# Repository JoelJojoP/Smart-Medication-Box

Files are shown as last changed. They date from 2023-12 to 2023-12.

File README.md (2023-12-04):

# Smart-Medication-Box

## Introduction

A considerable percentage of the elderly population takes medicines regularly. Sometimes, they forget to take their medication, which may lead to severe repercussions. This project aims to enhance medication adherence by developing a medicine box with personalized reminders for users to take their medications at user-defined times.

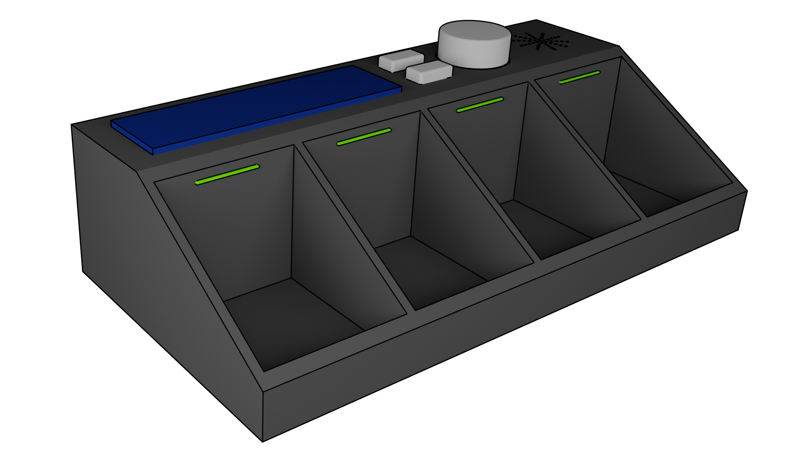
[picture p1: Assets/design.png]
Concept Design


## Technologies Used

Tech Used

## Implementation

- The whole project is based on Teensy 4.1 microcontroller.
- Users can set, modify or remove reminders using the rotary encoders and push button on the box.
- The box can give visual and auditory alerts using the LEDs on each rack and the buzzer.
- The inbuilt RTC of the microcontroller helps in keeping track of time.
- The user data and preferences are stored on an SD card attached to the Teensy.
- A 3D printed case is created to house all the electronics.

## Schematics

The circuit has been made on Fritzing. [Here](/Circuit_Diagram.fzz) is the Fritzing file.

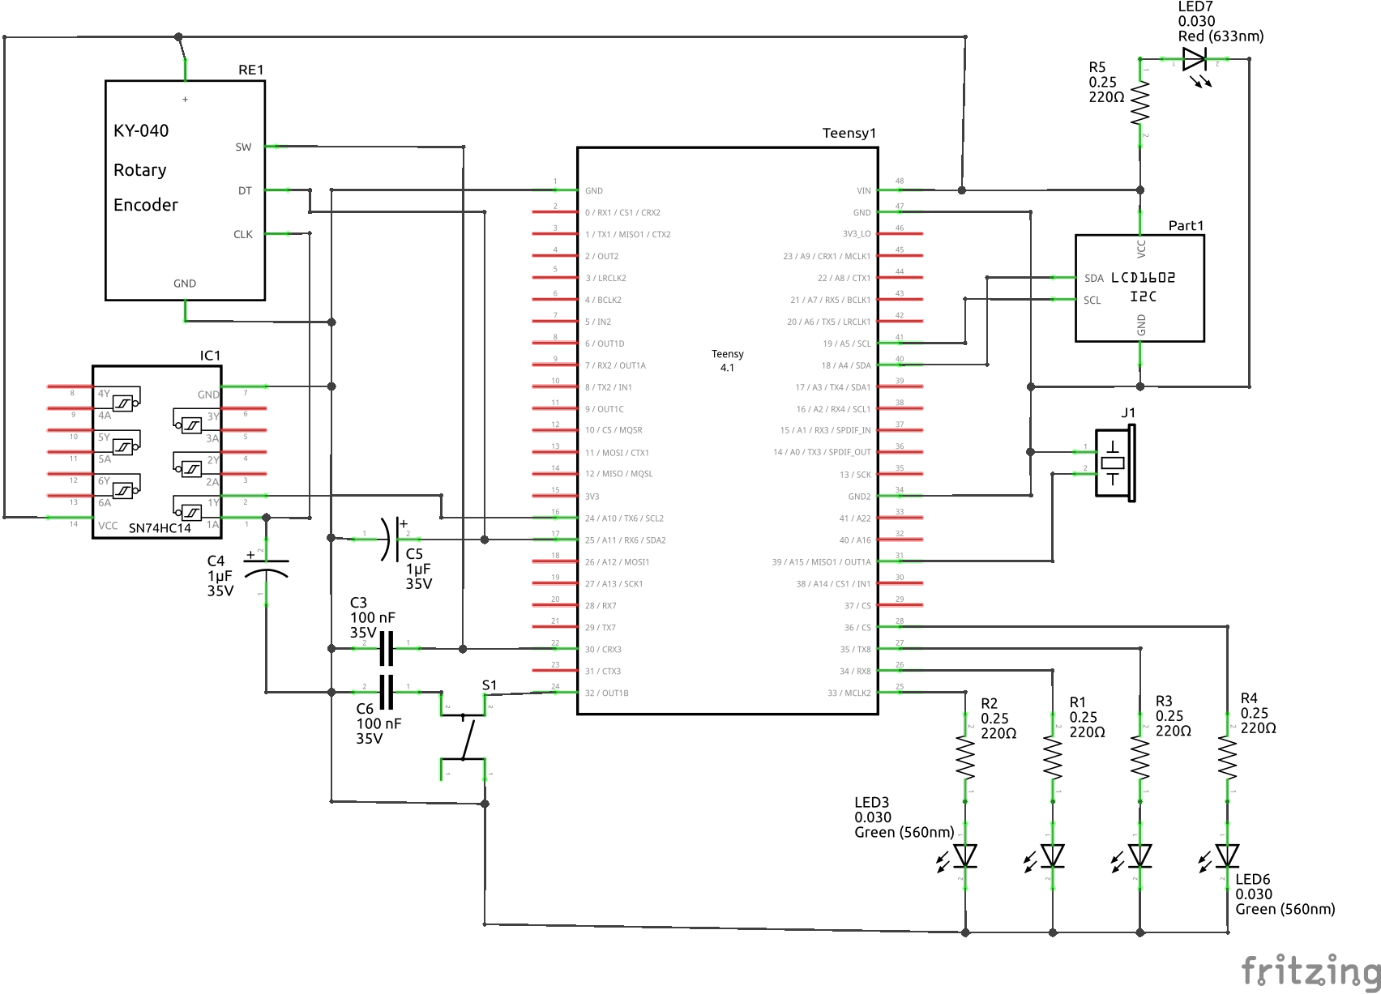
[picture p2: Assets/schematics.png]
Schematics


> **Note:**
> - We have wired the clk of the rotary encoder to a 7414 Hex Schmitt Trigger IC because the signals from the encoders were noisy. This is not necessary and the clk of the encoder can be wired directly to the teensy if the rotary encoder works fine.
> - Other than these connections, make sure to hook up a coin cell Li-Ion battery to the VBat pin right behind the SD card slot. This battery will be used to power the RTC even when the Teensy is switched off.

## Design of the Medication Box

The medication box was designed in OnShape. The ```.stl``` files can be taken from [here](/Models). To edit the model, [here](https://cad.onshape.com/documents/3bb37c6f5c3fc5625ebe736c/w/5e6eef892a42bb9e06b4f36b/e/434df4fac0757aec08d6021b) is the link to the OnShape document.

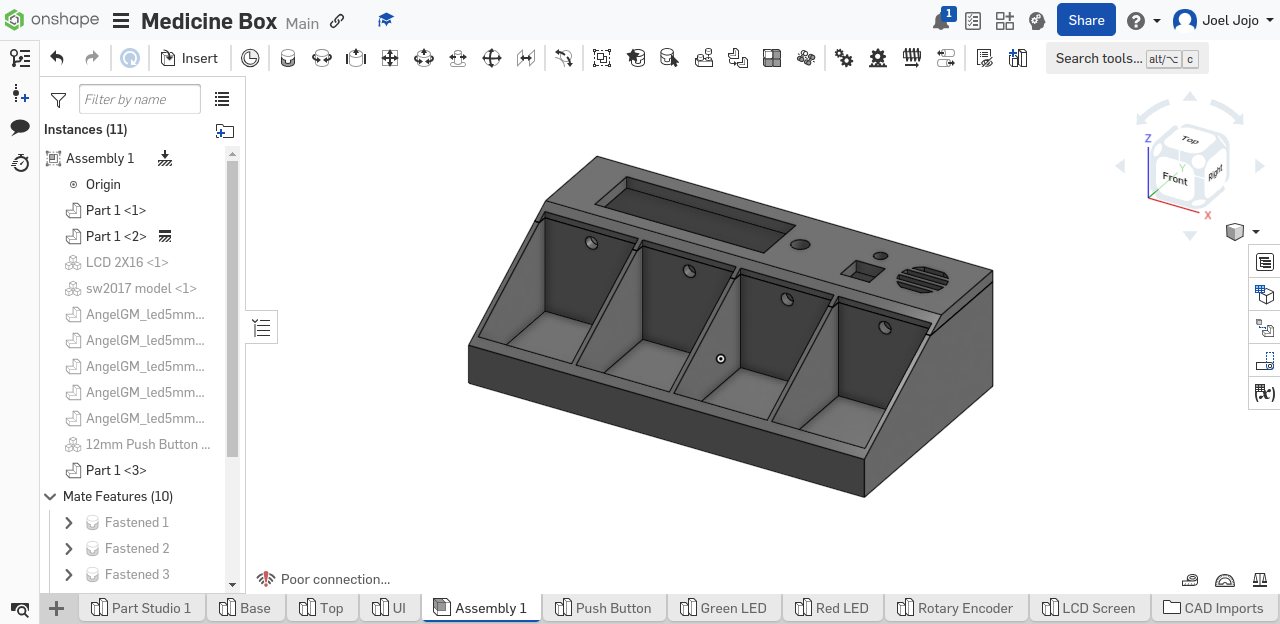
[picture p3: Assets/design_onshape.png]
Model


## Everything Put Together

After testing the circuits, rigging the circuit on a perfboard and placing all the components inside the 3D print, this is how it looks at the end.

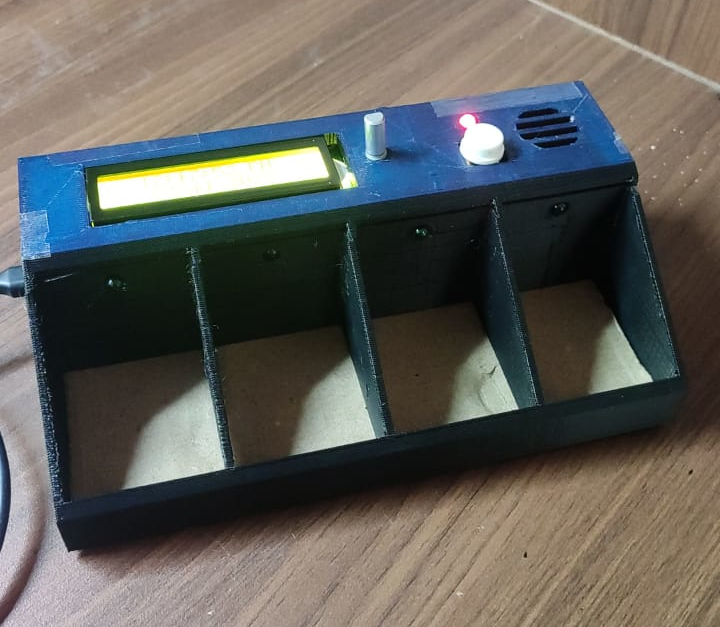
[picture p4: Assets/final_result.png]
Final Result


## Future Scope

- Improving portability by using rechargeable batteries.
- Integrating the medication box with mobile applications.
- Enable IoT connectivity toprovide remote monitoring features for healthcare providers.
- Implement machine learning to provide personalized insights and predictions to optimize medication adherence.
- Extend the capabilities of the medication box to accommodate a broader range of medication types.

## Project Members

1. [Joel Jojo Painuthara](https://github.com/JoelJojoP)
2. [Jalak Jignesh Kamdar](https://github.com/jalakjk13)

## License

This repository is licensed under the [MIT License](https://github.com/JoelJojoP/Smart-Medication-Box/blob/main/LICENSE)

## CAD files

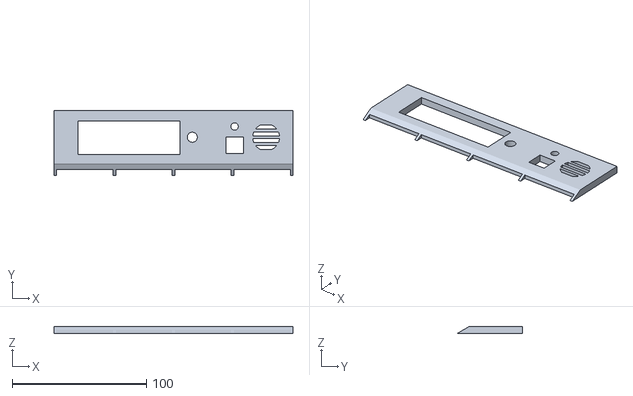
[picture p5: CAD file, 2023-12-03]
Models/Top.stl
178.0 x 48.6 x 5.00

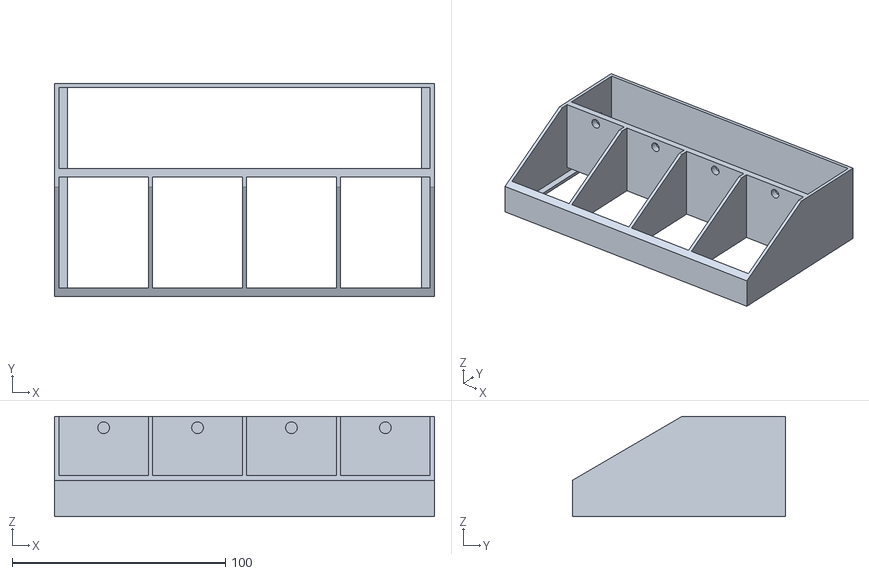
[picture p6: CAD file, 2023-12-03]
Models/Body.stl
178.0 x 100.0 x 47.0

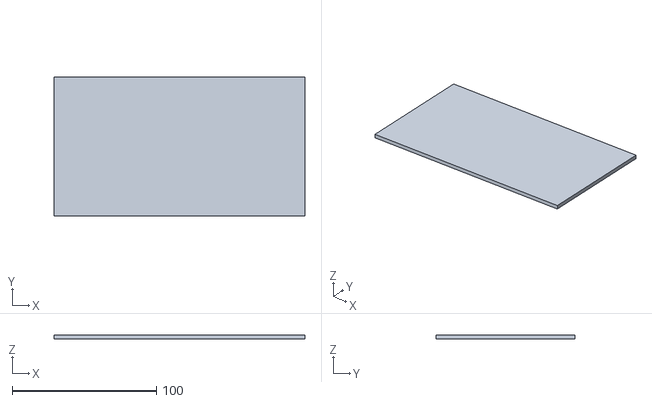
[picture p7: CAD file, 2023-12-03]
Models/Base.stl
173.8 x 96.0 x 3.00

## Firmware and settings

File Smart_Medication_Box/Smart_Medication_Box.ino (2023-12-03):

// Teensy 4.1 code for Smart Medication Box

#include <Wire.h>
#include <LiquidCrystal_I2C.h>
#include <TimeLib.h>
#include <SD.h>
#include <SPI.h>

#define TIME_HEADER "T"

// Pins for various components
#define enc_clk 24
#define enc_dt 25
#define menu_button 32
#define select_button 30
#define buzzer_pin 39
int Rack_LED[4] = {33, 34, 35, 36};

// SD Card chip select - BUILTIN_SDCARD to use the built-in SD card slot of Teensy 4.1
const int chipSelect = BUILTIN_SDCARD;

// File object for SD card
File myFile;

// LCD object - 0x27 is the default I2C address of the I2C LCD module
LiquidCrystal_I2C lcd(0x27, 16, 2); // set the LCD address to 0x27 for a 16 chars and 2 line display

// Variables for various state controls
volatile int state = 0;
volatile int substate = 0;
volatile int rack = 0;
volatile int time_slot = 0;
volatile int reset_opt = 0;
volatile int edit_mode = 0;
int alert[4] = {0, 0, 0, 0};

String isEvening = "AM";
int h, m, prev_h, prev_m;
String r_buff;
int write_change = 0;

// Arrays to store the time for each rack
int slot_hour[4][4] = {{0, 0, 0, 0}, {0, 0, 0, 0}, {0, 0, 0, 0}, {0, 0, 0, 0}};
int slot_minute[4][4] = {{0, 0, 0, 0}, {0, 0, 0, 0}, {0, 0, 0, 0}, {0, 0, 0, 0}};
String slot_script[4][4] = {{"AM", "AM", "AM", "AM"}, {"AM", "AM", "AM", "AM"}, {"AM", "AM", "AM", "AM"}, {"AM", "AM", "AM", "AM"}};

// Functions to get time from Teensy's inbuilt RTC
time_t getTeensy3Time()
{
  return Teensy3Clock.get();
}

unsigned long processSyncMessage()
{
  unsigned long pctime = 0L;
  const unsigned long DEFAULT_TIME = 1357041600;

  if (Serial.find(TIME_HEADER))
  {
    pctime = Serial.parseInt();
    return pctime;
    if (pctime < DEFAULT_TIME)
    {
      pctime = 0L;
    }
  }
  return pctime;
}

// Function to print digits on LCD
void printDigits(int digits)
{
  if (digits < 10)
    lcd.print("0");
  lcd.print(digits);
}

// State control functions
void change_option()
{
  if (digitalRead(enc_dt) == 0)
  {
    if (state == 1 && substate == 0)
    {
      rack--;
      if (rack <= -1)
        rack = 3;
    }
    else if (substate == 1)
    {
      time_slot--;
      if (time_slot <= -1)
        time_slot = 3;
    }
    else if (substate == 2)
    {
      if (edit_mode == 0)
      {
        slot_hour[rack][time_slot]--;
        if (slot_hour[rack][time_slot] <= -1)
          slot_hour[rack][time_slot] = 12;
      }
      else if (edit_mode == 1)
      {
        slot_minute[rack][time_slot]--;
        if (slot_minute[rack][time_slot] <= -1)
          slot_minute[rack][time_slot] = 59;
      }
      else if (edit_mode == 2)
      {
        slot_script[rack][time_slot] = (slot_script[rack][time_slot] == "AM") ? "PM" : "AM";
      }
    }
  }
  else
  {
    if (state == 1 && substate == 0)
    {
      rack++;
      if (rack >= 4)
        rack = 0;
    }
    else if (substate == 1)
    {
      time_slot++;
      if (time_slot >= 4)
        time_slot = 0;
    }
    else if (substate == 2)
    {
      if (edit_mode == 0)
      {
        slot_hour[rack][time_slot]++;
        if (slot_hour[rack][time_slot] >= 13)
          slot_hour[rack][time_slot] = 0;
      }
      else if (edit_mode == 1)
      {
        slot_minute[rack][time_slot]++;
        if (slot_minute[rack][time_slot] >= 60)
          slot_minute[rack][time_slot] = 0;
      }
      else if (edit_mode == 2)
      {
        slot_script[rack][time_slot] = (slot_script[rack][time_slot] == "AM") ? "PM" : "AM";
      }
    }
  }
}

void change_state()
{
  if (digitalRead(menu_button) == 0)
  {
    int f = 0;
    for (int i = 0; i < 4; i++)
    {
      if (alert[i] != 0)
      {
        alert[i] = 0;
        f = 1;
      }
    }
    if (f == 0)
    {
      substate = 0;
      state++;
      if (state == 2)
        state = 0;
    }
  }
}

void select_opt()
{
  if (digitalRead(select_button) == 0 && state == 1 && substate == 0)
  {
    substate = 1;
  }
  else if (digitalRead(select_button) == 0 && substate == 1)
  {
    substate = 2;
  }
  else if (digitalRead(select_button) == 0 && substate == 2)
  {
    edit_mode++;
    if (edit_mode == 3)
    {
      substate = 1;
      edit_mode = 0;
      write_change = 1;
    }
  }
}

// Function to sound the alarm
void alarm()
{
  for (int i = 0; i < 4; i++)
  {
    if (alert[i] >= 1 && alert[i] <= 200)
    {
      digitalWrite(Rack_LED[i], alert[i] % 2);
      digitalWrite(buzzer_pin, alert[i] % 2);
      alert[i]++;
    }
    else
    {
      alert[i] = 0;
      digitalWrite(Rack_LED[i], LOW);
      digitalWrite(buzzer_pin, LOW);
    }
  }
}

void setup()
{
  Serial.begin(9600);
  pinMode(menu_button, INPUT_PULLUP);
  pinMode(select_button, INPUT_PULLUP);
  pinMode(enc_clk, INPUT);
  pinMode(enc_dt, INPUT_PULLUP);
  pinMode(buzzer_pin, OUTPUT);
  for (int i = 0; i < 4; i++)
  {
    pinMode(Rack_LED[i], OUTPUT);
    digitalWrite(Rack_LED[i], LOW);
  }
  while (!SD.begin(chipSelect))
  {
    digitalWrite(LED_BUILTIN, HIGH);
  }
  setSyncProvider(getTeensy3Time);
  lcd.init();
  lcd.backlight();
  lcd.setCursor(2, 0);
  lcd.print("Smart Med Box");
  myFile = SD.open("setting.txt");
  int i = 0, j = 0;

  // Reading the time slots from the SD card
  while (myFile.available())
  {
    char c = myFile.read();
    if (c == ',')
    {
      if (r_buff != "")
      {
        if (i < 4)
          slot_hour[i][j] = r_buff.toInt();
        else if (i < 8)
          slot_minute[i - 4][j] = r_buff.toInt();
        else if (i < 12)
          slot_script[i - 8][j] = r_buff;
        j++;
        if (j == 4)
        {
          i++;
          j = 0;
        }
      }
      r_buff = "";
    }
    else
      r_buff = r_buff + c;
  }
  delay(2000);
  lcd.clear();
  attachInterrupt(digitalPinToInterrupt(enc_clk), change_option, FALLING);
  attachInterrupt(digitalPinToInterrupt(menu_button), change_state, FALLING);
  attachInterrupt(digitalPinToInterrupt(select_button), select_opt, FALLING);
}

void loop()
{
  // Set time to system time when uploading code to Teensy
  if (Serial.available())
  {
    time_t t = processSyncMessage();
    if (t != 0)
    {
      Teensy3Clock.set(t);
      setTime(t);
    }
  }

  // Convert time from 24 hour format to 12 hour format
  isEvening = "AM";
  h = hour();
  if (h > 12)
  {
    h = h - 12;
    isEvening = "PM";
  }
  else if (h == 0)
    h = 12;
  else if (h == 12)
    isEvening = "PM";
  m = minute();
  lcd.clear();

  // Display everything on the LCD screen
  if (substate == 1)
  {
    lcd.setCursor(1, 0);
    printDigits(slot_hour[rack][0]);
    lcd.print(":");
    printDigits(slot_minute[rack][0]);
    lcd.print(slot_script[rack][0]);
    lcd.setCursor(1, 1);
    printDigits(slot_hour[rack][1]);
    lcd.print(":");
    printDigits(slot_minute[rack][1]);
    lcd.print(slot_script[rack][1]);
    lcd.setCursor(9, 0);
    printDigits(slot_hour[rack][2]);
    lcd.print(":");
    printDigits(slot_minute[rack][2]);
    lcd.print(slot_script[rack][2]);
    lcd.setCursor(9, 1);
    printDigits(slot_hour[rack][3]);
    lcd.print(":");
    printDigits(slot_minute[rack][3]);
    lcd.print(slot_script[rack][3]);
    if (time_slot == 0)
    {
      lcd.setCursor(0, 0);
      lcd.print(">");
    }
    else if (time_slot == 1)
    {
      lcd.setCursor(0, 1);
      lcd.print(">");
    }
    else if (time_slot == 2)
    {
      lcd.setCursor(8, 0);
      lcd.print(">");
    }
    else if (time_slot == 3)
    {
      lcd.setCursor(8, 1);
      lcd.print(">");
    }
  }
  else if (substate == 2)
  {
    lcd.setCursor(5, 0);
    printDigits(slot_hour[rack][time_slot]);
    lcd.print(":");
    printDigits(slot_minute[rack][time_slot]);
    lcd.print(slot_script[rack][time_slot]);
    if (edit_mode == 0)
    {
      lcd.setCursor(5, 1);
      lcd.print("^^");
    }
    else if (edit_mode == 1)
    {
      lcd.setCursor(8, 1);
      lcd.print("^^");
    }
    else if (edit_mode == 2)
    {
      lcd.setCursor(10, 1);
      lcd.print("^^");
    }
  }
  else if (state == 0)
  {
    lcd.setCursor(2, 0);
    printDigits(h);
    lcd.print(":");
    printDigits(m);
    lcd.print(":");
    printDigits(second());
    lcd.print(" ");
    lcd.print(isEvening);
    lcd.setCursor(3, 1);
    lcd.print(day());
    lcd.print("/");
    lcd.print(month());
    lcd.print("/");
    lcd.print(year());
  }
  else if (state == 1)
  {
    lcd.setCursor(1, 0);
    lcd.print("Rack 1");
    lcd.setCursor(1, 1);
    lcd.print("Rack 2");
    lcd.setCursor(10, 0);
    lcd.print("Rack 3");
    lcd.setCursor(10, 1);
    lcd.print("Rack 4");
    if (rack == 0)
    {
      lcd.setCursor(0, 0);
      lcd.print(">");
    }
    else if (rack == 1)
    {
      lcd.setCursor(0, 1);
      lcd.print(">");
    }
    else if (rack == 2)
    {
      lcd.setCursor(9, 0);
      lcd.print(">");
    }
    else if (rack == 3)
    {
      lcd.setCursor(9, 1);
      lcd.print(">");
    }
  }

  // Write changes time slots to the SD card
  if (write_change == 1)
  {
    myFile = SD.open("setting.txt", FILE_WRITE_BEGIN);
    if (myFile)
    {
      for (int i = 0; i < 4; i++)
      {
        for (int j = 0; j < 4; j++)
        {
          myFile.print(",");
          myFile.print(slot_hour[i][j]);
        }
      }
      myFile.println(" ");
      for (int i = 0; i < 4; i++)
      {
        for (int j = 0; j < 4; j++)
        {
          myFile.print(",");
          myFile.print(slot_minute[i][j]);
        }
      }
      myFile.println(" ");
      for (int i = 0; i < 4; i++)
      {
        for (int j = 0; j < 4; j++)
        {
          myFile.print(",");
          myFile.print(slot_script[i][j]);
        }
      }
      myFile.println(",");
    }
    myFile.close();
    write_change = 0;
  }

  // Check if the time matches with the time slot and sound the alarm
  if (m != prev_m)
  {
    for (int i = 0; i < 4; i++)
    {
      for (int j = 0; j < 4; j++)
      {
        if (slot_hour[i][j] == h && slot_script[i][j] == isEvening && slot_minute[i][j] == m)
        {
          alert[i] = 1;
        }
      }
    }
  }

  prev_m = m;
  prev_h = h;
  alarm();
  delay(300);
}
